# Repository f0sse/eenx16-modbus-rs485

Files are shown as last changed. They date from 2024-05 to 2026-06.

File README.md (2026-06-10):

Projektfiler för kandidatarbetet "Demand Side Flexibility in Electrical Heating Systems" på Chalmers 2024.

# Modbus

I detta träd finns ritningar och kod för en Raspberry Pi 4 HAT ämnad att prata
Modbus över RS485.

## Raspberry Pi 4

Lägg till följande i filen `/boot/config.txt`, under taggen `[pi4]`:

	dtoverlay=disable-bt
	dtoverlay=uart4,ctsrts
	dtparam=uart0=off
	dtparam=uart1=off
	enable_uart=0

Kör `systemctl disable hciuart` som root.

I filen `/boot/cmdline.txt`, se till att ta bort alla boot consoles som
refererar till `ttyAMA*`, och se till att raden innehåller
`plymouth.ignore-serial-consoles`.

För att dubbelkolla att hardware flow control är på för uart4, kör
`raspi-gpio get 8-11` och kolla att följande tabell stämmer.

| Funktion | GPIO | Pin |
|---:|:----:|:---:|
| TX | 8  |  24 |
| RX | 9  |  21 |
| CTS |  10  |  19 |
| RTS |  11  |  23 |

## HAT

För att samla in data från de tre elmätarna i labbet, använder vi oss av en
egen-designad Raspberry Pi-HAT, som sköter seriell kommunikation med en[MAX483]
(https://www.analog.com/en/products/max483.html) och temperaturläsningar med
en [DS18B20](https://www.analog.com/en/products/ds18b20.html) (monterad på en
extern modul).

För att prata Modbus användes [libmodbus](https://libmodbus.org) och ett eget
program skrivet i C för att samla in momentan och total effekt för samtliga
faser på de tre elmätarna i interval om 5 sekunder, och skicka dessa data till
en tidsseriedatabas.

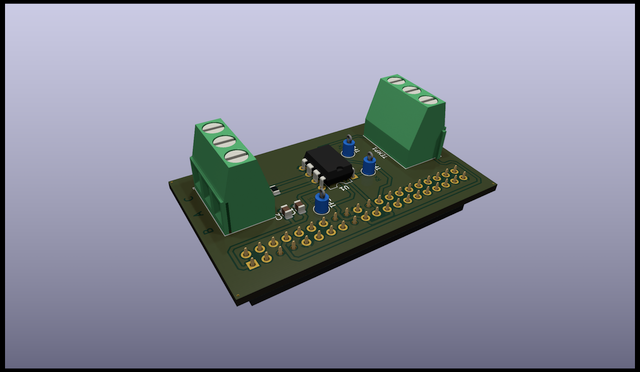
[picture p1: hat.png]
3D-rendering av kretskortet


Alla design-filer finns under `/hat`.

## Misc

MAX483 gör det möjligt för oss att kommunicera enligt RS-485, men chippet kräver
att man sätter pinnarna 2-3 höga vid Tx och låga vid Rx.

Problemet med RPI var att en vanlig UART endast har pinnar för Rx/Tx, och inga
möjligheter att automatiskt kontrollera de nödvändiga pinnarna på något sätt.

Lyckligtvis har RPI 4 möjlgheter till hardware flow control, så den pinne man
sätter som Request To Send (RTS) kan användas till att sätta pinnarna 2-3
istället för det tänkta användningsområdet. Libmodbus var också skrivet runt
denna tanken för dess RTU-driver. På så vis kan man använda RPI  4 och uppåt,
och prata Modbus med endast dess UART.

`influx.c` innehåller ett mindre polerat bibliotek för att skriva mätdata till
[InfluxDB](https://www.influxdata.com) genom biblioteket [CURL](https://curl.se).

`modbus.c` använder libmodbus för att fråga tre olika
elmätare om fasvärden för spänning, ström, aktiv effekt och så vidare. För mer
information om vilka register som används, se manualen som ligger i mappen
`doc`.

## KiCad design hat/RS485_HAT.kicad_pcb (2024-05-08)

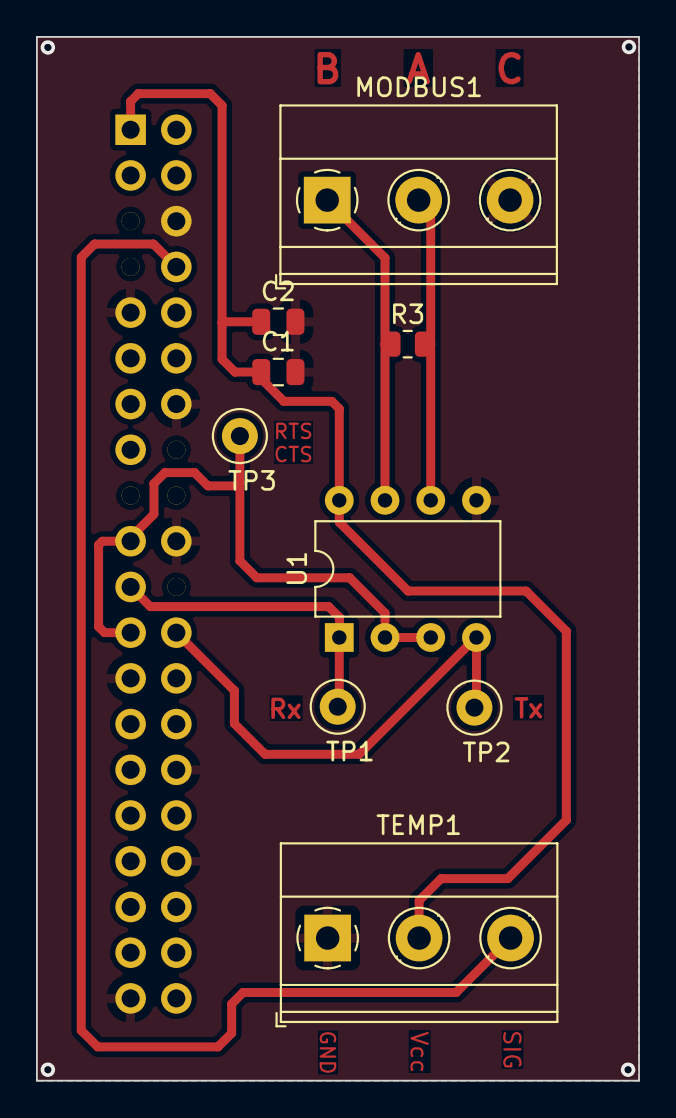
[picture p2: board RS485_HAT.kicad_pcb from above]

Board: 2 copper layers, 33.5 x 58.0 mm, 10 parts (1 on the bottom side), 8 nets.

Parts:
C1: 10 uF; C_0805_2012Metric
C2: 100 nF; C_0805_2012Metric
J1: Raspberry_Pi_2_3; PinSocket_2x20_P2.54mm_Vertical
MODBUS1: Screw_Terminal_01x03; TerminalBlock_Phoenix_MKDS-1,5-3-5.08_1x03_P5.08mm_Horizont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
R3: 120 Ω; R_0805_2012Metric
TEMP1: Screw_Terminal_01x03; TerminalBlock_Phoenix_MKDS-1,5-3-5.08_1x03_P5.08mm_Horizont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
TP1: Rx; TestPoint_Loop_D1.80mm_Drill1.0mm_Beaded
TP2: Tx; TestPoint_Loop_D1.80mm_Drill1.0mm_Beaded
TP3: RTS/CTS; TestPoint_Loop_D1.80mm_Drill1.0mm_Beaded
U1: MAX483E; DIP-8_W7.62mm

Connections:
/SIG: J1.8 (GPIO14/TXD), TEMP1.3
GND: C1.2, C2.2, J1.6 (GND), J1.9 (GND), J1.14 (GND), J1.20 (GND), J1.25 (GND), J1.30 (GND), J1.34 (GND), J1.39 (GND), MODBUS1.3, TEMP1.1, U1.5 (GND)
unnamed: J1.21 (MISO0/GPIO9), TP1.1, U1.1 (RO)
unnamed: J1.19 (MOSI0/GPIO10), J1.23 (SCLK0/GPIO11), TP3.1, U1.2 (~RE), U1.3 (DE)
unnamed: J1.24 (~CE0/GPIO8), TP2.1, U1.4 (DI)
unnamed: MODBUS1.1, R3.1, U1.7 (B)
unnamed: MODBUS1.2, R3.2, U1.6 (A)
VCC: C1.1, C2.1, J1.1 (3V3), J1.17 (3V3), TEMP1.2, U1.8 (VCC)
